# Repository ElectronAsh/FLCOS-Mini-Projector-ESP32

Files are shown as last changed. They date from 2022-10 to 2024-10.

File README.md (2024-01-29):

# FLCOS Mini Projector with ESP32 and Composite input.

WARNING: Please do not build this board yet. There are still some checks to do.

UPDATE: 29th April 2023: I finally bought one of the Jakks toy projectors from eBay US.
I hooked up the USB Logic Analyzer to the "SPI" bus on the projector's FLCOS module.
The projector only ever write to three registers after power-up, then another register to enable the FLCOS after a video signal is detected.

So I did a few tweaks to my Arduino code, and now my own board works, too. ;)

I also confirmed that the AliExpress FLCOS modules DO indeed work fine in the Jakks projector, so they are the same/compatible part.

There are still a few issues to sort out, where the FLCOS won't always turn on when you first plug USB power in, but it will work after pulling
the reset (EN_N) Low on the ESP32, or re-flashing via the Arduino IDE.

I've included a few photos below of the projector showing "Gex" on the 3DO.
This is a PAL 3DO, so I tweaked the Arduino code to fit the projected image better.
(the FLCOS registers will default to NTSC, so I tweaked the values for PAL.)

TODO...

Voltage reg pinouts and ADJ pins (use adjustable and add resistor dividers, or look for fixed-output regs for the BOM?)
FPC connector direction, top contact? (The FLCOS module will be mounted upside-down on the board)
Double-check the JST ZH pinout for the LEDs. DONE
Maybe change the pin header to some sort of socket for the Composite input? DONE
Check availability of all ICs on LCSC or Mouser, digikey etc. DONE
Hunt for parts, create a BOM. DONE
Run ERC and DRC. DONE
Order a few test PCBs. DONE

This is a driver board for the FLCOS mini projector modules on AliExpress...
https://www.aliexpress.com/item/1005003386129982.html

There is a forum post here, with the full datasheet for what appears to be the same FLCOS chip used on the AliExpress module.
https://whycan.com/t_2420.html

("datasheet" is actually the product brief. "cps" has all of the register settings.)

The pinout of the lower flex cable on post #4 of the forum seems to match up with the ribbon on the FLCOS module.

The pinout of the RGB LED cable on the module is a bit strange.
There is no correlation between the wire colours, the silkscreen designators, and the RGB LED chip itself.

I tested the RGB LED with a bench PSU, though, and the pinout on the Eagle schematic *should* be correct now.
I just need to double-check that the JST ZH connector for the LED is not rotated 180-degrees or something.

(it's possible the manufacturer changed the RGB LED for a different one on request, which is why the LED cable pinout doesn't seem to tally with the silkscreen?)

The exact maximum LED current is unknown.
I tested one of the Green LEDs with 160mA at first, and it didn't seem to increase in brightness much above 200mA.

The forward voltage drop of the Blue and Green LEDs was around 3.3 Volts, according to my bench PSU (when current-limiting). (there are two Green LEDs on the die) 

The forward voltage drop of the Red LED was around 2.0 Volts.

The included RGB LED has all of Anodes connected together.
I originally put some LM3404 LED driver ICs on the board, but they wouldn't have worked for a common-Anode RGB LED chip, so I changed those for the LM3414 instead.

The FLCOS module appears to be the same one used in the "JAKKS Eyeclops" toy projector...
https://videotechnology.blogspot.com/2010/11/inside-jakks-pacific-eyeclops-mini.html

Before I received some modules, I did a lot of tracing of the JAKKS PCB to try to confirm the pinout against the TVP5150 TV decoder chip.
The pinout seemed to match up with the forum post above.

There was a discussion on Twitter in 2021 about these modules, too...
https://twitter.com/AshEvans81/status/1498184526236987392?s=20&t=zDXLWlJON1HiXY-NYlLocg

The PCB layout was also discussed on the #lab channel of bitluni's Discord server.

bitluni's awesome ESP32 VGA output project was the reason I wanted to add an ESP32 to the board.
It could make for a neat mini movie player or similar (streaming low-res files from SD card.)

https://github.com/bitluni/ESP32Lib/blob/8f4b1bc9c331546c57c1ee837ac37303b8d8739c/examples/VGADemo14Bit/VGADemo14Bit.ino

(bitluni's code is untested with the FLCOS modules atm, but I think it will work OK with a few tweaks. The FLCOS chip accepts video input as sequential R,G,B bytes.)

I kept the TVP5150 chip on the board, as this is the same chip used in the JAKKS projector.
It outputs standard bt.656 style digital video, and accepts Composite input.

(The TVP5150 can receive both NTSC and PAL Composite, using one 14.318 MHz crystal.)

Only the TVP5150 or ESP32 can drive the FLCOS module at any one time.
The TVP chip can set it's output pins to High-Z (this is done via an I2C register), so it should be possible to keep both the ESP32 and TVP5150 onboard.

Most of the footprint libraries for the ESP32, SD slot, TVP5150, and LM3414 were taken from existing open-source projects.
I don't have the names or links to all of those projects now, but I will add them to the README if I can find them.

I used Eagle 9.0.1 to do the PCB layout.

Build at your own risk!

It does finally "work" now, in terms of getting Composite video to display.
But there are a few issues, as mentioned in the update at the top of this README.

I haven't tried generating video on the ESP32 yet, so I'm not 100% sure that will work without PCB changes.

ElectronAsh. ;)

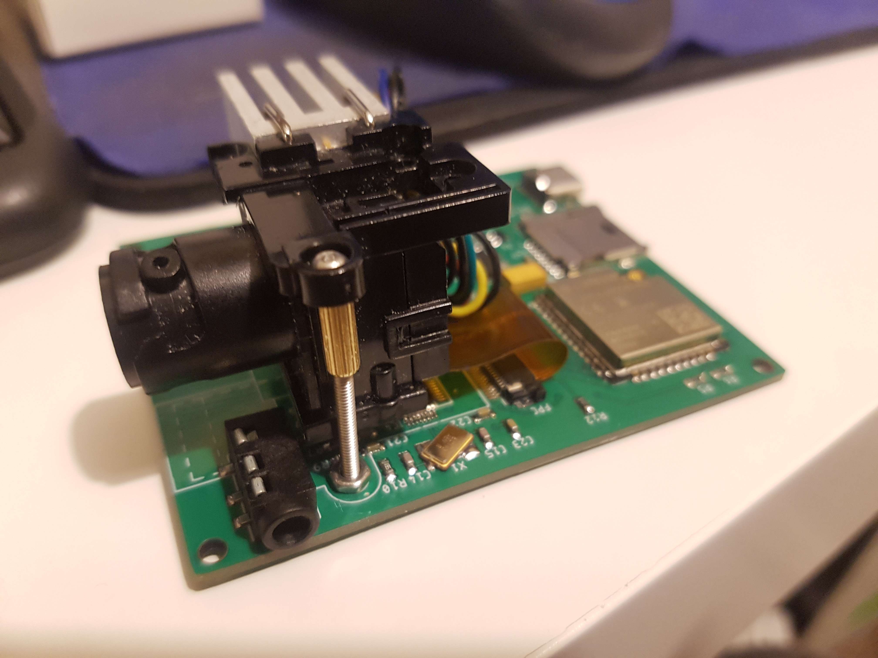
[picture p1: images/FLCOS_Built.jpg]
FLCOS First Light - GEX Logo

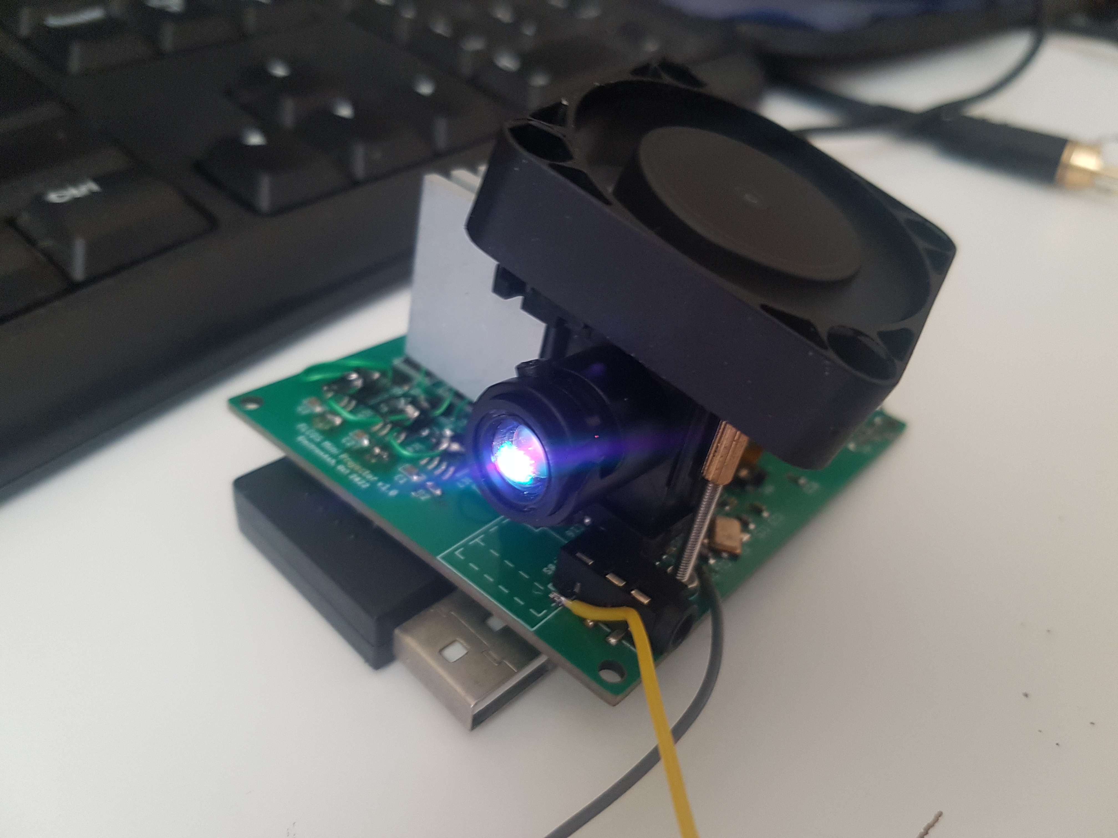
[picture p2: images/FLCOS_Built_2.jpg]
FLCOS First Light - GEX Logo

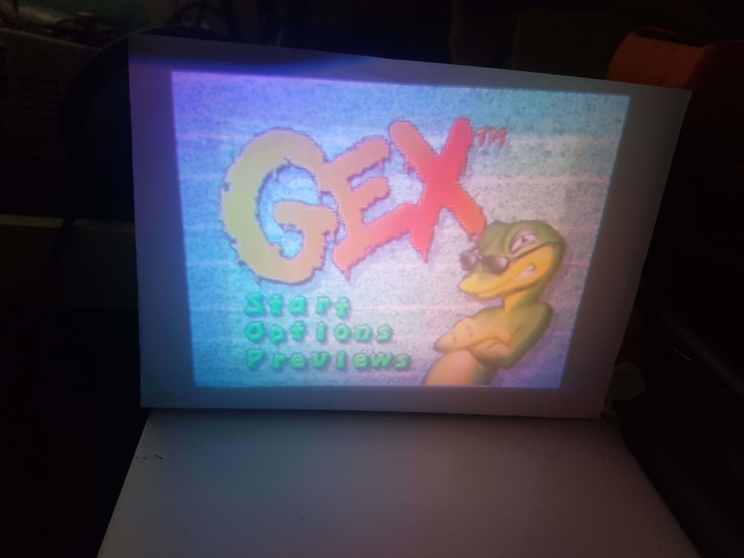
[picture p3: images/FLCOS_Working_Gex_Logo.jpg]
FLCOS First Light - GEX Logo


This was a quick test of the Green LEDs. FLCOS chip itself is not powered.

Both Green LEDs in parallel, 220mA, lens was 150mm from the "screen".
The box is only 90mm wide.

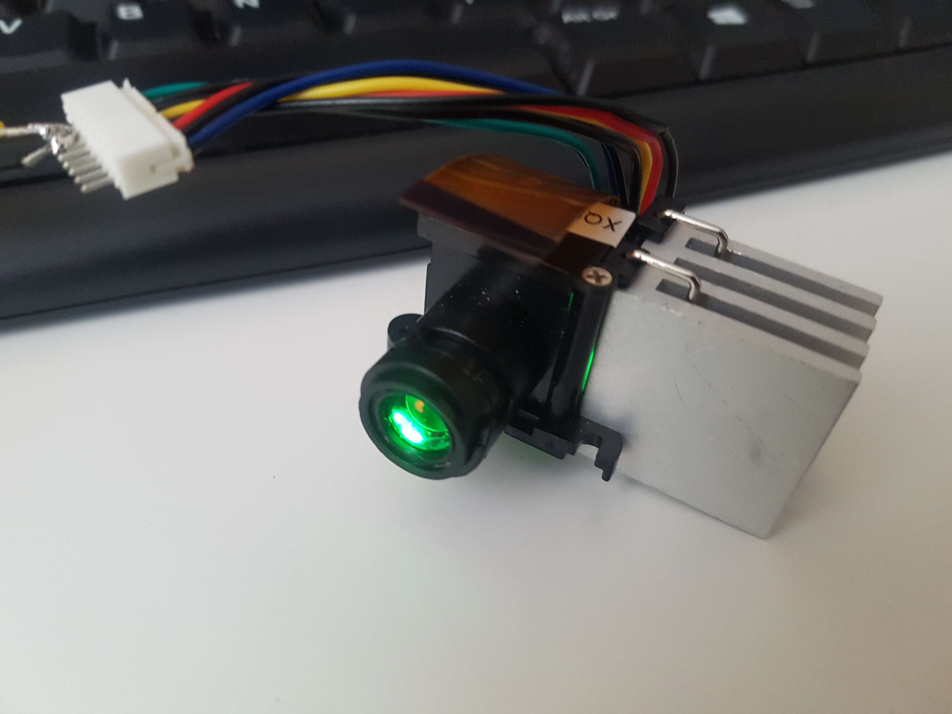
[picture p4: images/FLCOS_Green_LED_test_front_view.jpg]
FLCOS Green LED test front view

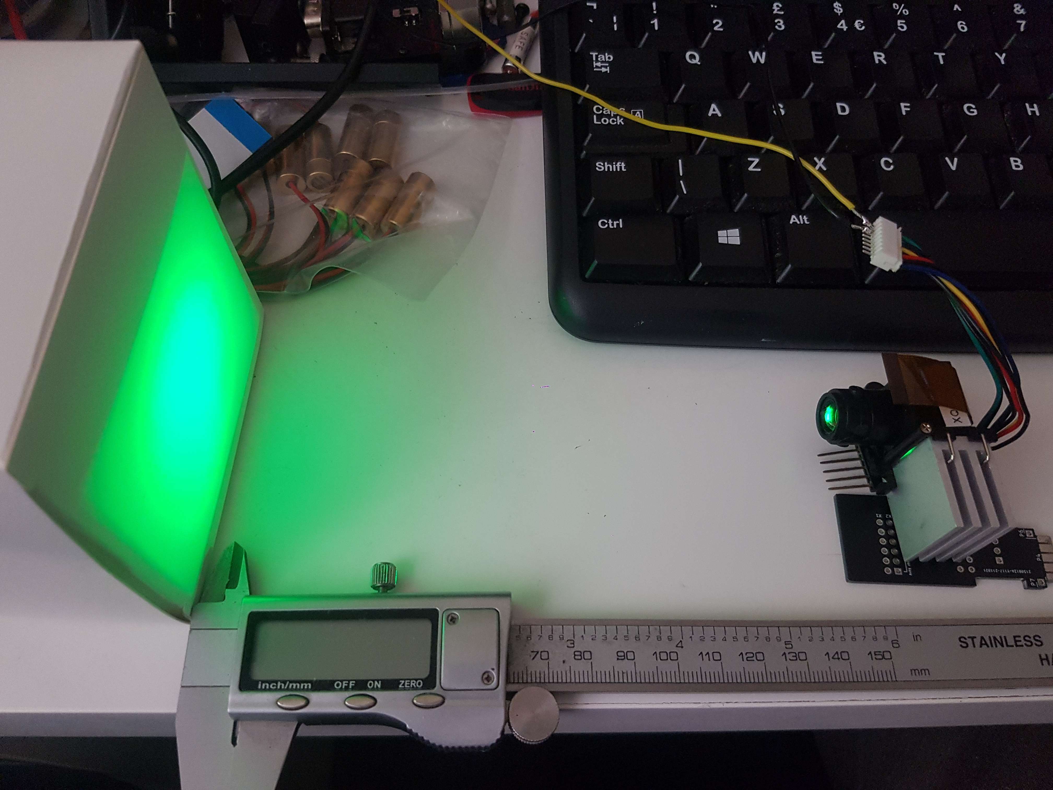
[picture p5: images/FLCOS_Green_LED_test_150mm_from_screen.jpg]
FLCOS Green LED test 150mm from screen

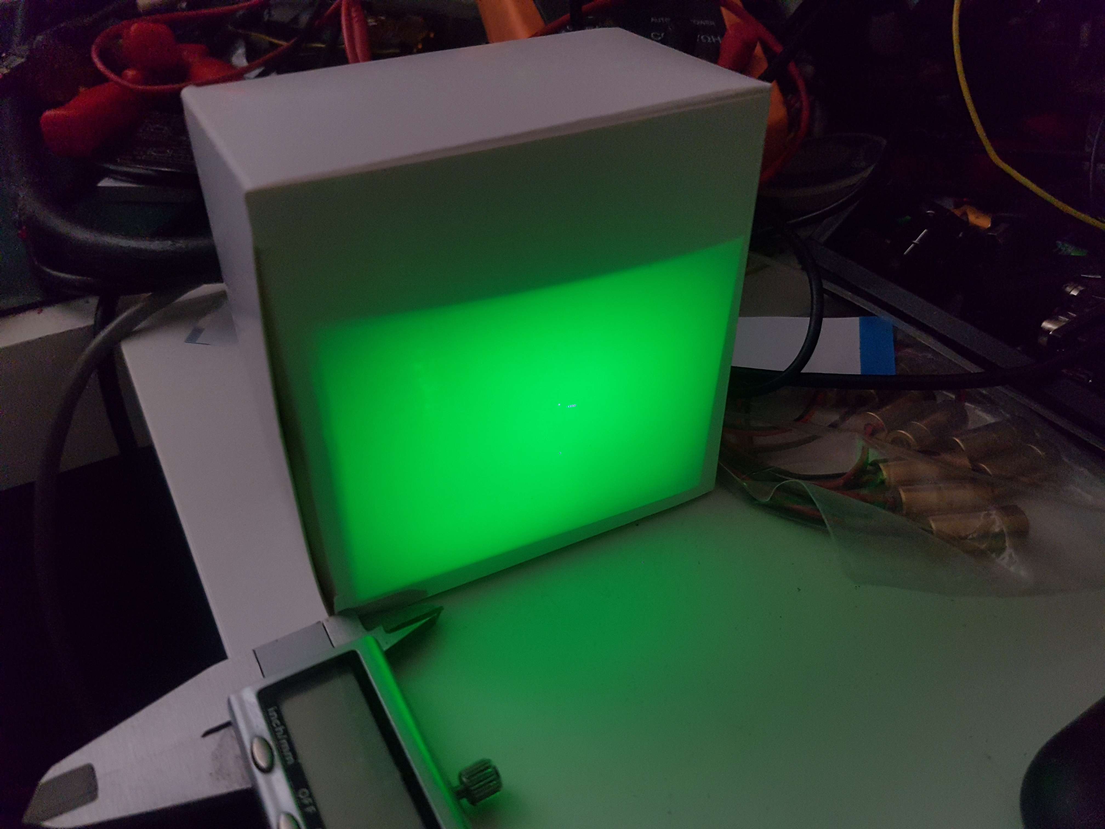
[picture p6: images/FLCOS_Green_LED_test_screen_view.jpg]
FLCOS Green LED test screen view


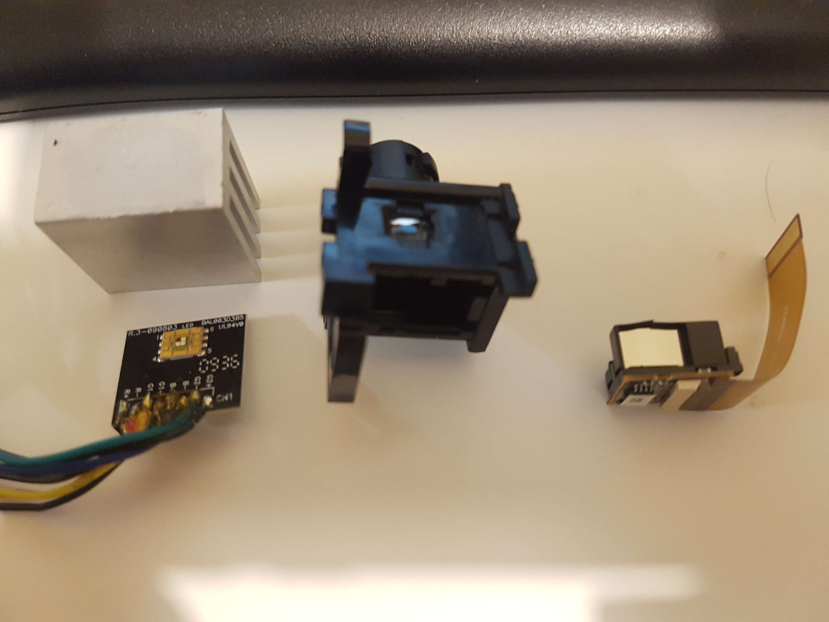
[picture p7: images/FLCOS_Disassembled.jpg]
FLCOS Module Disassembled


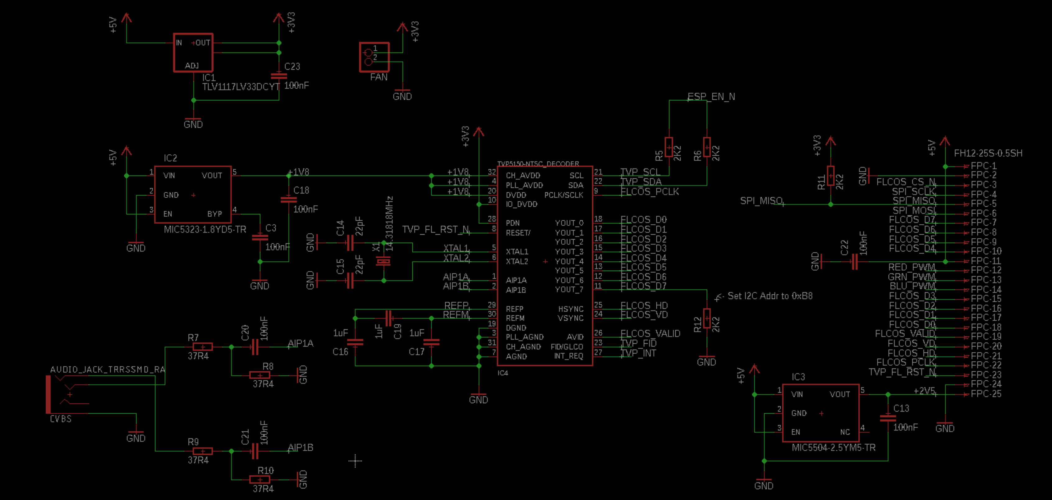
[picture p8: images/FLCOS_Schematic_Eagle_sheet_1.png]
FLCOS Schematic Eagle sheet 1

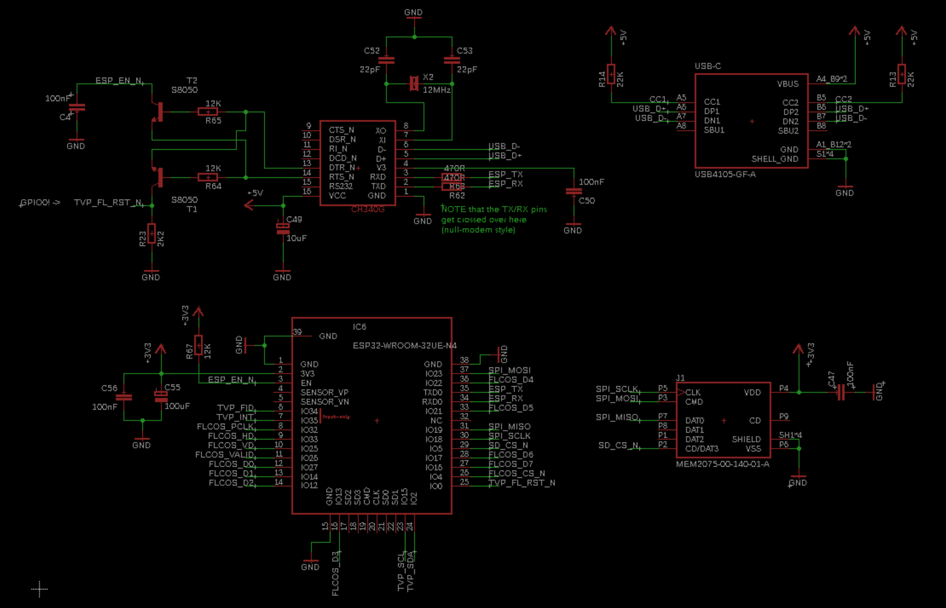
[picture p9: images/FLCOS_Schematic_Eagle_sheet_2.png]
FLCOS Schematic Eagle sheet 2

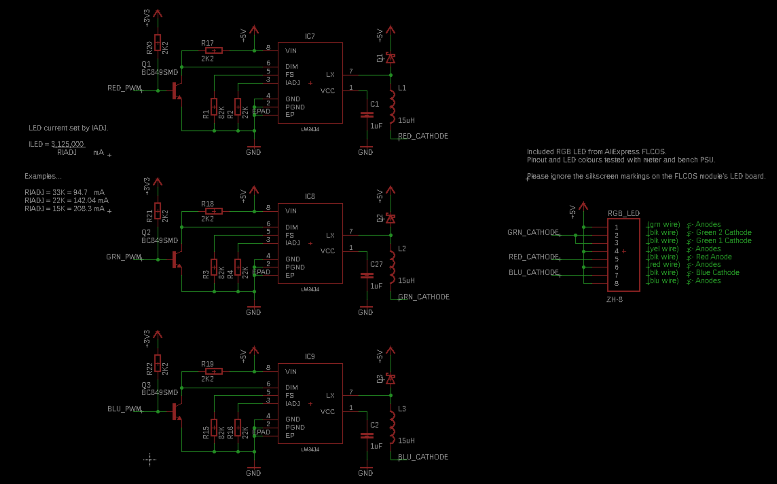
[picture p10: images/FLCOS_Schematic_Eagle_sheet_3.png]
FLCOS Schematic Eagle sheet 3

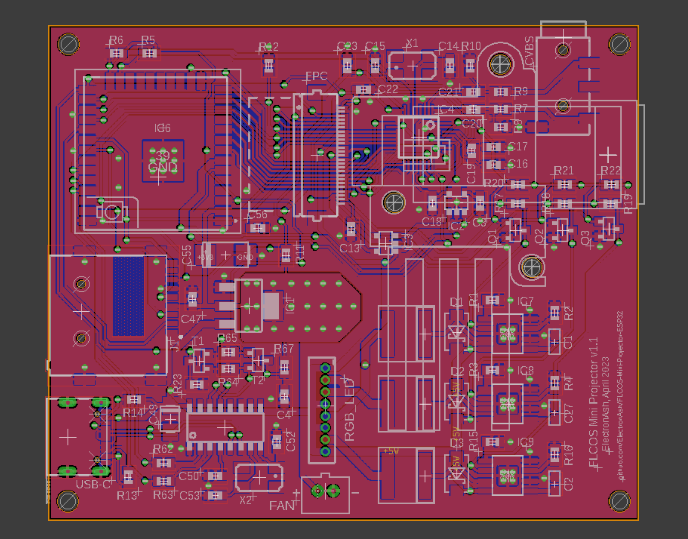
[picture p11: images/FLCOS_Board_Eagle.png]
FLCOS Green LED test - front view


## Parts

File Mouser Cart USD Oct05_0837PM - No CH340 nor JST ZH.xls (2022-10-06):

SHOPPING CART
This is not an invoice
05-Oct-22 20:37:14
 | Mouser # | Mfr. # | Manufacturer | Customer # | Description | RoHS | Lifecycle | Order Qty. | Price (USD) | Ext.: (USD)
1 | 187-CL10B105KA8NNNL | CL10B105KA8NNNL | Samsung Electro-Mechanics |  | Multilayer Ceramic Capacitors MLCC - SMD/SMT 1uF+/-10% 25V X7R 16 0603 | RoHS Compliant |  | 6 | $0.10 | $0.60
2 | 187-CL10B104MA8NNWC | CL10B104MA8NNWC | Samsung Electro-Mechanics |  | Multilayer Ceramic Capacitors MLCC - SMD/SMT 100nF+/-20% 25V X7R 0603 | RoHS Compliant |  | 10 | $0.031 | $0.31
3 | 187-CL10C220JB8NNWC | CL10C220JB8NNWC | Samsung Electro-Mechanics |  | Multilayer Ceramic Capacitors MLCC - SMD/SMT 22pFC0G +/-5% 50v 06 0603 | RoHS Compliant | New Product | 4 | $0.10 | $0.40
4 | 581-TAJB106M016R | TAJB106M016RNJ | KYOCERA AVX |  | Tantalum Capacitors - Solid SMD 16V 10uF 20% 1210 ESR= 2.8 Ohm | RoHS Compliant |  | 1 | $0.37 | $0.37
5 | 581-TAJC107K006SNJ | TAJC107K006SNJ | KYOCERA AVX |  | Tantalum Capacitors - Solid SMD 6.3V 100uF 2312 ESR=900mOhms 10% | RoHS Compliant |  | 1 | $0.67 | $0.67
6 | 603-RT0603DRE0782KL | RT0603DRE0782KL | YAGEO |  | Thin Film Resistors - SMD | RoHS Compliant By Exemption |  | 3 | $0.10 | $0.30
7 | 603-RT0603DRE0722KL | RT0603DRE0722KL | YAGEO |  | Thin Film Resistors - SMD 22K Ohm 0.5% 1/10W 75 Volts 50ppm | RoHS Compliant By Exemption |  | 5 | $0.12 | $0.60
8 | 603-RT0603DRE072K2L | RT0603DRE072K2L | YAGEO |  | Thin Film Resistors - SMD 2.2K Ohm 0.5% 1/10W 75 Volts 50ppm | RoHS Compliant By Exemption |  | 4 | $0.11 | $0.44
9 | 603-RC0603FR-0737R4L | RC0603FR-0737R4L | YAGEO |  | Thick Film Resistors - SMD 37.4 Ohms 100 mW 0603 1% | RoHS Compliant By Exemption |  | 5 | $0.10 | $0.50
10 | 603-RT0603FRE07470RL | RT0603FRE07470RL | YAGEO |  | Thin Film Resistors - SMD 1/10W 470 ohm 1% 50ppm | RoHS Compliant By Exemption |  | 2 | $0.10 | $0.20
11 | 603-RT0603FRE0712KL | RT0603FRE0712KL | YAGEO |  | Thin Film Resistors - SMD 1/10W 12K ohm 1% 50ppm | RoHS Compliant By Exemption |  | 2 | $0.10 | $0.20
12 | 875-TYS6028150M-10 | TYS6028150M-10 | Laird Performance Materials |  | Power Inductors - SMD 15uH 20% -40C +125C | RoHS Compliant |  | 3 | $0.53 | $1.59
13 | 241-SB34AFCAUR1000A1 | SB34AFC-AU_R1_000A1 | Panjit |  | Schottky Diodes & Rectifiers 40V SchottkyF-C 3A | RoHS Compliant By Exemption | New Product | 3 | $0.45 | $1.35
14 | 833-MMSS8050-H-TP | MMSS8050-H-TP | Micro Commercial Components (MCC) |  | Bipolar Transistors - BJT 625mW, 25V, 1500mA | RoHS Compliant |  | 2 | $0.21 | $0.42
15 | 595-TLV1117LV33DCYT | TLV1117LV33DCYT | Texas Instruments |  | LDO Voltage Regulators 1A,Pos Fix Vltg LDO Linear Reg | RoHS Compliant |  | 1 | $1.14 | $1.14
16 | 998-MIC5323-1.8YD5TR | MIC5323-1.8YD5-TR | Microchip |  | LDO Voltage Regulators 300mA uCap ULDO High PSRR Low Noise Regulator | RoHS Compliant |  | 1 | $0.68 | $0.68
17 | 998-MIC5504-2.5YM5TR | MIC5504-2.5YM5-TR | Microchip |  | LDO Voltage Regulators Single 300mA LDO with Enable Pull-Down & Auto Discharge | RoHS Compliant |  | 1 | $0.16 | $0.16
18 | 926-LM3414HVMR/NOPB | LM3414HVMR/NOPB | Texas Instruments |  | LED Lighting Drivers COMM ANODE CAP CONST CRNT BUCK LED DRVR | RoHS Compliant |  | 3 | $2.48 | $7.44
19 | 595-TVP5150AM1PBSR | TVP5150AM1PBSR | Texas Instruments |  | Video ICs Ultralo Pwr NTSC/PAL SECAM Vid Decoder | RoHS Compliant |  | 1 | $6.56 | $6.56
20 | 356-ESP32WRM32UE32UH | ESP32-WROOM-32UE-N4 | Espressif |  | Multiprotocol Modules SMD module ESP32-WROOM-32UE, ESP32-D0WD-V3, ESP32 ECO V3, 4 MB SPI flash, IPEX antenna connector | RoHS Compliant |  | 1 | $3.00 | $3.00
21 | 640-MEM20750014001A | MEM2075-00-140-01-A | Global Connector Technology (GCT) |  | Memory Card Connectors Micro SD Push-Push, SMT, 1.40mm Profile, With Peg, Open Switch, T&R | RoHS Compliant | New Product | 1 | $1.96 | $1.96
22 | 640-USB4105-GF-A | USB4105-GF-A | Global Connector Technology (GCT) |  | USB Connectors USB Type C,2.0, Rec,SMT, 0.95mmTH Shell Stakes,G/F,RA,Top Mnt,T&R | RoHS Compliant | New Product | 1 | $0.81 | $0.81
23 | 649-SFV25R-2STE1HLF | SFV25R-2STE1HLF | FCI / Amphenol |  | FFC & FPC Connectors FFC/FPC CONN | RoHS Compliant |  | 1 | $0.62 | $0.62
24 | 520-ECS143-20-23A-EN | ECS-143-20-23A-EN-TR | ECS |  | Crystals 14.31818MHz 20pF ECX-64A | RoHS Compliant |  | 1 | $1.13 | $1.13
25 | 520-120-12-36AGN-TR3 | ECS-120-12-36-AGN-TR3 | ECS |  | Crystals 12MHz,CL 12,TOL +/-25 ppm,STAB +/-30 ppm,-40 +85 C,ESR 150O | RoHS Compliant | New Product | 1 | $0.37 | $0.37
26 | 474-PRT-12639 | PRT-12639 | SparkFun Electronics |  | SparkFun Accessories Audio Jack - 3.5mm TRRS (SMD) |  |  | 1 | $0.95 | $0.95
By submitting your order you agree to these terms and conditions. (https://www.mouser.com/saleterms) |  |  |  |  |  |  |  |  | Merchandise: | $32.77
Prices are reflected at the date and time shown. |  |  |  |  |  |  |  |  | Shipping Charge: | $7.99

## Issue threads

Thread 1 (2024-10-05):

How I can control this FLCoS display using esp32?

FeatheryVlad, 2024-10-05:
Hello! Could you please tell me how I can control this FLCoS display using esp32? And Is it possible to get by with just one board based on the esp32-s3 chip?

Also I really like your project, I just can’t imagine how long it took to develop it.

ElectronAsh, 2024-10-05:
Hi,

I never did get around to driving the FLCOS module from the ESP32.
I only ever tested it using the PAL/NTSC decoder on the board.

The FLCOS module needs a bt.656 style video stream, which is an 8-bit bus, commonly used in TV broadcast, cable boxes, DVD players, etc.

Sometimes bt.656 can have separate syncs, or the sync is actually embedded into the 8-bit data.

I'm not sure where to start with writing the ESP32 code for that, sorry.

(I was hoping maybe bitluni might be interested, but he's often super busy. hehe)

Regards,
Ash.

FeatheryVlad, 2024-10-05:
Thank you!

Sorry, but unfortunately I have no experience working with a display other than those usually sold on Aliexpress (spi, i2c, etc.)
That’s why I had this question, yes, I looked at your code and board diagram many times (even very many times), but I still can’t understand how it works for you

Also I would like to know more about BT.656 from you, since there is little useful information on the Internet, maybe it has something to do with my region/country

Please, I really want to run it :)

FeatheryVlad, 2024-10-06:
Hi,

I literally can't do anything, neither write registers via SPI, much less send a frame.
I'm using ESP-IDF to flash my esp32-s3-zero, but still can't get SPI configured correctly even with your code and Arduino IDE.

I also searched online, but didn't find anything similar to this repository.

Please forgive me for these requests, I literally don't know who I could contact with such a question😭.

Regards,
Vlad.

ElectronAsh, 2024-10-07:
Hi,

My board uses a TVP5150, which is a PAL/NTSC decoder chip.

Currently, the ESP32 on the board is used purely to configure some basic commands on the FLCOS module at power-up.

The ESP32 itself does not drive the video signals on the FLCOS.
I never got quite that far with the project.

Instead, I input Composite Video into the TVP5150.
That chip sends the bt.656 style video to the FLCOS module directly.
The ESP32 doesn't get involved at all after that.

I'm not sure where to start with using the ESP32 to send video to the FLCOS.
I was looking at using bitluni's VGA code as a basis, then trying to add the bt.656 stuff to the output to the FLCOS.

The TVP5150 can output bt.656 with or without embedded Syncs.
I believe I was using separate Hsync/Vsync to drive the FLCOS.

Even when using Composite Video input and the TVP chip, I had some trouble getting the FLCOS to initialize correctly every time.

I had to solder a Reset button to the ESP32 on my board, and hit Reset just after power-up, then the FLCOS sprang to life.

I used the Composite video output from a 3DO console to test things.

Unless you are using the TVP or a board like mine, I think it could be hard to send video direct from an ESP32.
In theory, though, you could try sending "raw" RGB values to the FLCOS, and generate Pclk/Hsync/Vsync/Valid signals, and it might then display something?

(then you would need to convert those RGB values into Y,U,V samples, to get the correct colours on the FLCOS.)

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

ElectronAsh, 2024-10-07:
Oh, btw...

I posted quite a lot of info on the FLCOS project on "The Coriolis Effect" Discord.

Here is an invite link, I believe it is free-to-join...
https://discord.gg/sRQVjWkK

(if the link doesn't work for you, somebody else has probably clicked on it already, so please let me know. lol)

You should fine a whole thread on the "projects-threaded" channel called "FLCOS Mini Projector".

1w0, 2025-02-03:
Hi, thanks for sharing the project and insights, wondering if I can join the server as well? Thanks!

By the way, I haven't been able to access the datasheet as mentioned being in the forum, will be great if there is any alternative 🙏

FeatheryVlad, 2025-02-10:
Hi,
As far as I remember this is exactly the datasheet:
http://file.whycan.com/files/members/1606/ldm_0201_e3_cps.pdf

ElectronAsh, 2025-02-11:
Here's an invite link to the Discord server.

But if anyone else clicks it in the meantime, I think it stops working?

https://discord.gg/89Uxe6wU

AFAIK, it's a public server anyway.

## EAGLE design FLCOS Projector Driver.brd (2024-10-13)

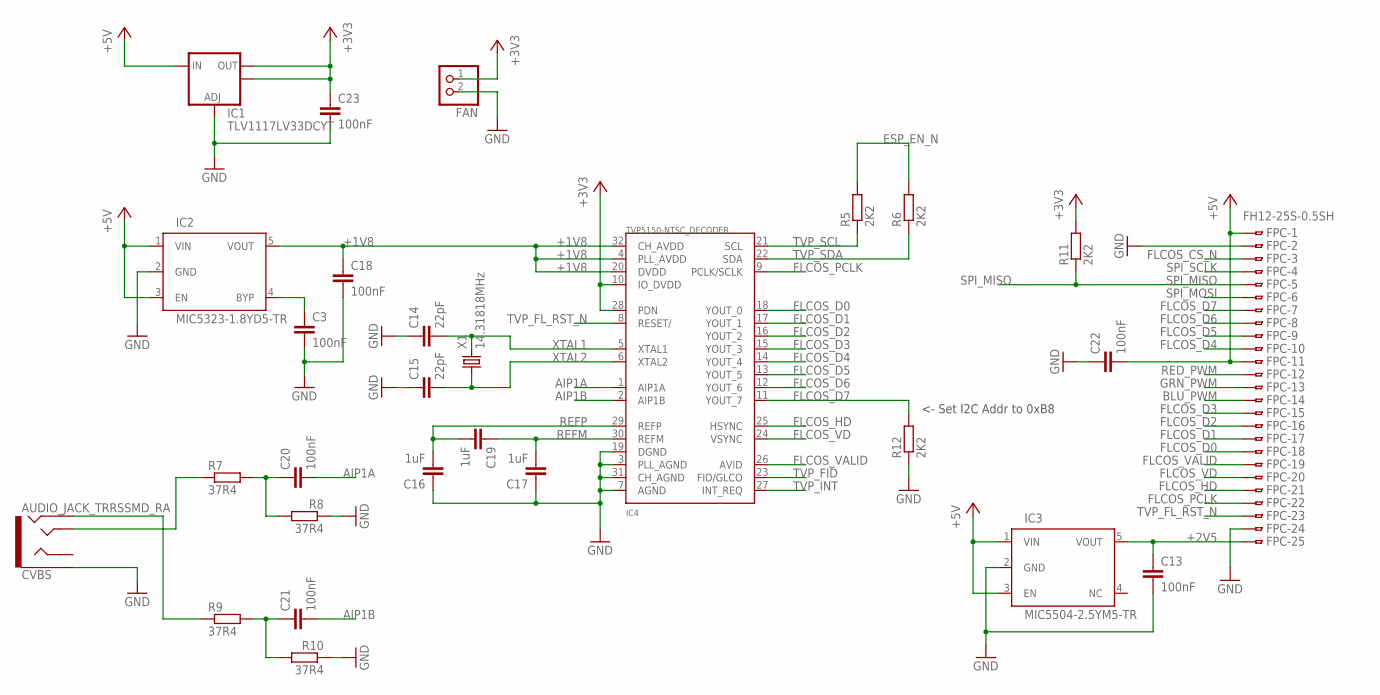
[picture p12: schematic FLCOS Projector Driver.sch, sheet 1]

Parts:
C3, C13, C18, C20, C21, C22, C23: 100nF; C0603
C14, C15: 22pF; C0603
C16, C17, C19: 1uF; C0603
CVBS: AUDIO_JACK_TRRSSMD_RA; AUDIO_JACK_3.5MM_TRRS_SMD_RA
FAN: JST_2PIN-THM; JST-PH-2-THM
FPC: FH12-25S-0.5SH
IC1: TLV1117LV33DCYT; SOT223
IC2: MIC5323-1.8YD5-TR; SOT23-5
IC3: MIC5504-2.5YM5-TR; SOT23-5
IC4: TVP5150-NTSC_DECODER; TQFP32-5MM
R5, R6, R11, R12: 2K2; R0603
R7, R8, R9, R10: 37R4; R0603
X1: 14.31818MHz; CTS406

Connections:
+1V8: C18.1, IC2.5 (VOUT), IC4.4 (PLL_AVDD), IC4.20 (DVDD), IC4.32 (CH_AVDD)
+2V5: C13.1, FPC.25, IC3.5 (VOUT)
+3V3: C23.1, FAN.1 (2), IC1.2 (OUT), IC1.4 (OUT), IC4.10 (IO_DVDD), IC4.28 (PDN), R11.2; also elsewhere on the board
+5V: C22.2, FPC.1, FPC.11, IC1.3 (IN), IC2.1 (VIN), IC2.3 (EN), IC3.1 (VIN), IC3.3 (EN); also elsewhere on the board
AIP1A: C20.2, IC4.1 (AIP1A)
AIP1B: C21.2, IC4.2 (AIP1B)
BLU_PWM: FPC.14; also elsewhere on the board
ESP_EN_N: R5.2, R6.2; also elsewhere on the board
FLCOS_CS_N: FPC.3; also elsewhere on the board
FLCOS_D0: FPC.18, IC4.18 (YOUT_0); also elsewhere on the board
FLCOS_D1: FPC.17, IC4.17 (YOUT_1); also elsewhere on the board
FLCOS_D2: FPC.16, IC4.16 (YOUT_2); also elsewhere on the board
FLCOS_D3: FPC.15, IC4.15 (YOUT_3); also elsewhere on the board
FLCOS_D4: FPC.10, IC4.14 (YOUT_4); also elsewhere on the board
FLCOS_D5: FPC.9, IC4.13 (YOUT_5); also elsewhere on the board
FLCOS_D6: FPC.8, IC4.12 (YOUT_6); also elsewhere on the board
FLCOS_D7: FPC.7, IC4.11 (YOUT_7), R12.2; also elsewhere on the board
FLCOS_HD: FPC.21, IC4.25 (HSYNC); also elsewhere on the board
FLCOS_PCLK: FPC.22, IC4.9 (PCLK/SCLK); also elsewhere on the board
FLCOS_VALID: FPC.19, IC4.26 (AVID); also elsewhere on the board
FLCOS_VD: FPC.20, IC4.24 (VSYNC); also elsewhere on the board
GND: C3.2, C13.2, C14.1, C15.1, C16.1, C17.1, C18.2, C22.1, C23.2, CVBS.EARTH, FAN.2 (1), FPC.2, FPC.24, IC1.1 (ADJ), IC2.2 (GND), IC3.2 (GND), IC4.3 (PLL_AGND), IC4.7 (AGND), IC4.19 (DGND), IC4.31 (CH_AGND), R8.1, R10.1, R12.1; also elsewhere on the board
GRN_PWM: FPC.13; also elsewhere on the board
unnamed: C3.1, IC2.4 (BYP)
unnamed: C21.1, R9.2, R10.2
unnamed: C20.1, R7.2, R8.2
unnamed: CVBS.TIP, R7.1
unnamed: CVBS.RING2, R9.1
RED_PWM: FPC.12; also elsewhere on the board
REFM: C17.2, C19.1, IC4.30 (REFM)
REFP: C16.2, C19.2, IC4.29 (REFP)
SPI_MISO: FPC.5, R11.1; also elsewhere on the board
SPI_MOSI: FPC.6; also elsewhere on the board
SPI_SCLK: FPC.4; also elsewhere on the board
TVP_FID: IC4.23 (FID/GLCO); also elsewhere on the board
TVP_FL_RST_N: FPC.23, IC4.8 (RESET/); also elsewhere on the board
TVP_INT: IC4.27 (INT_REQ); also elsewhere on the board
TVP_SCL: IC4.21 (SCL), R5.1; also elsewhere on the board
TVP_SDA: IC4.22 (SDA), R6.1; also elsewhere on the board
XTAL1: C14.2, IC4.5 (XTAL1), X1.3 (2)
XTAL2: C15.2, IC4.6 (XTAL2), X1.1

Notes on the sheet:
<- Set I2C Addr to 0xB8

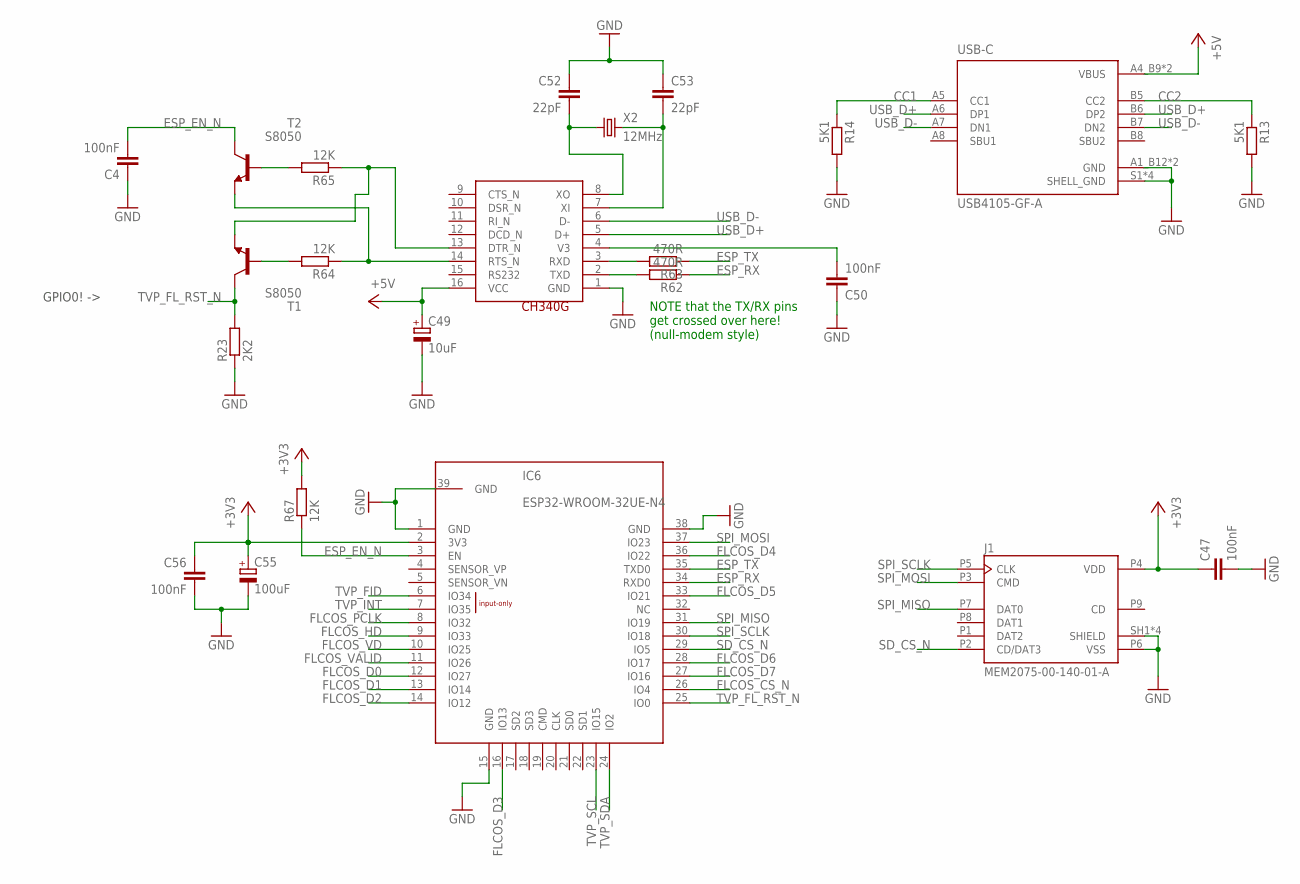
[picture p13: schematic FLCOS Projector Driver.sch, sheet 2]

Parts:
C4, C47, C50, C56: 100nF; C0603
C49: 10uF; B/3528-21W
C52, C53: 22pF; C0603
C55: 100uF; C/6032-28R
IC5: CH340G; SOIC16
IC6: ESP32-WROOM-32UE-N4; ESP32WROOM32D
J1: MEM2075-00-140-01-A; GCT_MEM2075-00-140-01-A
R13, R14: 5K1; R0603
R23: 2K2; R0603
R62, R63: 470R; R0603
R64, R65, R67: 12K; R0603
T1, T2: S8050; SOT23-BEC
USB-C: USB4105-GF-A; GCT_USB4105-GF-A
X2: 12MHz; CTS406

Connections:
+3V3: C47.1, C55.+, C56.1, IC6.2 (3V3), J1.P4 (VDD), R67.2; also elsewhere on the board
+5V: C49.+, IC5.16 (VCC), USB-C.A4_B9 (VBUS), USB-C.B4_A9 (VBUS); also elsewhere on the board
CC1: R14.1, USB-C.A5 (CC1)
CC2: R13.1, USB-C.B5 (CC2)
ESP_EN_N: C4.2, IC6.3 (EN), R67.1, T2.C; also elsewhere on the board
ESP_RX: IC6.34 (RXD0), R62.1
ESP_TX: IC6.35 (TXD0), R63.1
FLCOS_CS_N: IC6.26 (IO4); also elsewhere on the board
FLCOS_D0: IC6.12 (IO27); also elsewhere on the board
FLCOS_D1: IC6.13 (IO14); also elsewhere on the board
FLCOS_D2: IC6.14 (IO12); also elsewhere on the board
FLCOS_D3: IC6.16 (IO13); also elsewhere on the board
FLCOS_D4: IC6.36 (IO22); also elsewhere on the board
FLCOS_D5: IC6.33 (IO21); also elsewhere on the board
FLCOS_D6: IC6.28 (IO17); also elsewhere on the board
FLCOS_D7: IC6.27 (IO16); also elsewhere on the board
FLCOS_HD: IC6.9 (IO33); also elsewhere on the board
FLCOS_PCLK: IC6.8 (IO32); also elsewhere on the board
FLCOS_VALID: IC6.11 (IO26); also elsewhere on the board
FLCOS_VD: IC6.10 (IO25); also elsewhere on the board
GND: C4.1, C47.2, C49.-, C50.1, C52.1, C53.1, C55.-, C56.2, IC5.1 (GND), IC6.1 (GND), IC6.15 (GND), IC6.38 (GND), IC6.39 (GND), J1.P6 (VSS), J1.SH1 (SHIELD), J1.SH2 (SHIELD), J1.SH3 (SHIELD), J1.SH4 (SHIELD), R13.2, R14.2, R23.1, USB-C.A1_B12 (GND), USB-C.B1_A12 (GND), USB-C.S1 (SHELL_GND), USB-C.S2 (SHELL_GND), USB-C.S3 (SHELL_GND), USB-C.S4 (SHELL_GND); also elsewhere on the board
unnamed: IC5.2 (TXD), R62.2
unnamed: IC5.3 (RXD), R63.2
unnamed: R64.2, T1.B
unnamed: R65.2, T2.B
unnamed: IC5.14 (RTS_N), R64.1, T2.E
unnamed: IC5.13 (DTR_N), R65.1, T1.E
unnamed: C50.2, IC5.4 (V3)
unnamed: C53.2, IC5.7 (XI), X2.3 (2)
unnamed: C52.2, IC5.8 (XO), X2.1
SD_CS_N: IC6.29 (IO5), J1.P2 (CD/DAT3)
SPI_MISO: IC6.31 (IO19), J1.P7 (DAT0); also elsewhere on the board
SPI_MOSI: IC6.37 (IO23), J1.P3 (CMD); also elsewhere on the board
SPI_SCLK: IC6.30 (IO18), J1.P5 (CLK); also elsewhere on the board
TVP_FID: IC6.6 (IO34); also elsewhere on the board
TVP_FL_RST_N: IC6.25 (IO0), R23.2, T1.C; also elsewhere on the board
TVP_INT: IC6.7 (IO35); also elsewhere on the board
TVP_SCL: IC6.23 (IO15); also elsewhere on the board
TVP_SDA: IC6.24 (IO2); also elsewhere on the board
USB_D+: IC5.5 (D+), USB-C.A6 (DP1), USB-C.B6 (DP2)
USB_D-: IC5.6 (D-), USB-C.A7 (DN1), USB-C.B7 (DN2)

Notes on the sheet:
NOTE that the TX/RX pins get crossed over here! (null-modem style)
GPIO0! ->

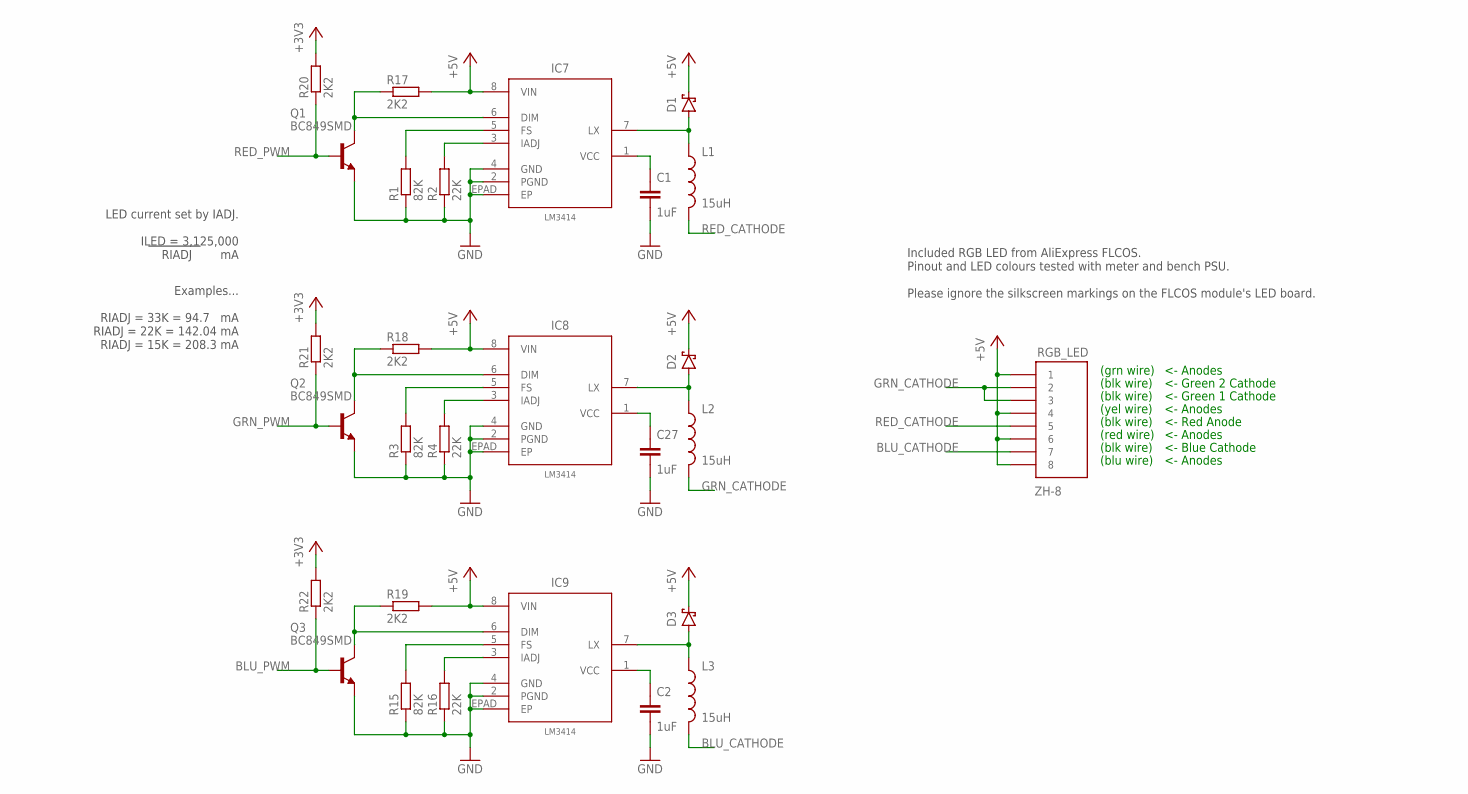
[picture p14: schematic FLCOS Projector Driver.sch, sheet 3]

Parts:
C1, C2, C27: 1uF; C0603
D1, D2, D3: "SB34AFC-AU_R1_000A1 SB34AFC-AU_R1_000A1"; SMA-DIODE-SCHOTTKY
IC7, IC8, IC9: LM3414; SO08-PAD
L1, L2, L3: 15uH; TAIYO-YUDEN-6X6X2.8
Q1, Q2, Q3: BC849SMD; SOT23-BEC
R1, R3, R15: 82K; R0603
R2, R4, R16: 22K; R0603
R17, R18, R19, R20, R21, R22: 2K2; R0603
RGB_LED: ZH-8

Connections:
+3V3: R20.2, R21.2, R22.2; also elsewhere on the board
+5V: D1.C, D2.C, D3.C, IC7.8 (VIN), IC8.8 (VIN), IC9.8 (VIN), R17.2, R18.2, R19.2, RGB_LED.1, RGB_LED.4, RGB_LED.6, RGB_LED.8; also elsewhere on the board
BLU_CATHODE: L3.2, RGB_LED.7
BLU_PWM: Q3.B, R22.1; also elsewhere on the board
GND: C1.2, C2.2, C27.2, IC7.2 (PGND), IC7.4 (GND), IC7.EPAD (EP), IC8.2 (PGND), IC8.4 (GND), IC8.EPAD (EP), IC9.2 (PGND), IC9.4 (GND), IC9.EPAD (EP), Q1.E, Q2.E, Q3.E, R1.1, R2.1, R3.1, R4.1, R15.1, R16.1; also elsewhere on the board
GRN_CATHODE: L2.2, RGB_LED.2, RGB_LED.3
GRN_PWM: Q2.B, R21.1; also elsewhere on the board
unnamed: IC7.6 (DIM), Q1.C, R17.1
unnamed: IC7.3 (IADJ), R2.2
unnamed: IC7.5 (FS), R1.2
unnamed: C1.1, IC7.1 (VCC)
unnamed: D1.A, IC7.7 (LX), L1.1
unnamed: IC9.3 (IADJ), R16.2
unnamed: IC9.5 (FS), R15.2
unnamed: C2.1, IC9.1 (VCC)
unnamed: D3.A, IC9.7 (LX), L3.1
unnamed: IC8.6 (DIM), Q2.C, R18.1
unnamed: IC9.6 (DIM), Q3.C, R19.1
unnamed: IC8.3 (IADJ), R4.2
unnamed: IC8.5 (FS), R3.2
unnamed: C27.1, IC8.1 (VCC)
unnamed: D2.A, IC8.7 (LX), L2.1
RED_CATHODE: L1.2, RGB_LED.5
RED_PWM: Q1.B, R20.1; also elsewhere on the board

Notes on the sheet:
(grn wire)
(blk wire)
(yel wire)
(red wire)
(blu wire)
<- Blue Cathode
<- Green 1 Cathode
<- Green 2 Cathode
<- Anodes
<- Red Anode
Included RGB LED from AliExpress FLCOS. Pinout and LED colours tested with meter and bench PSU. Please ignore the silkscreen markings on the FLCOS module's LED board.
LED current set by IADJ. ILED = 3,125,000 RIADJ mA
Examples... RIADJ = 33K = 94.7 mA RIADJ = 22K = 142.04 mA RIADJ = 15K = 208.3 mA

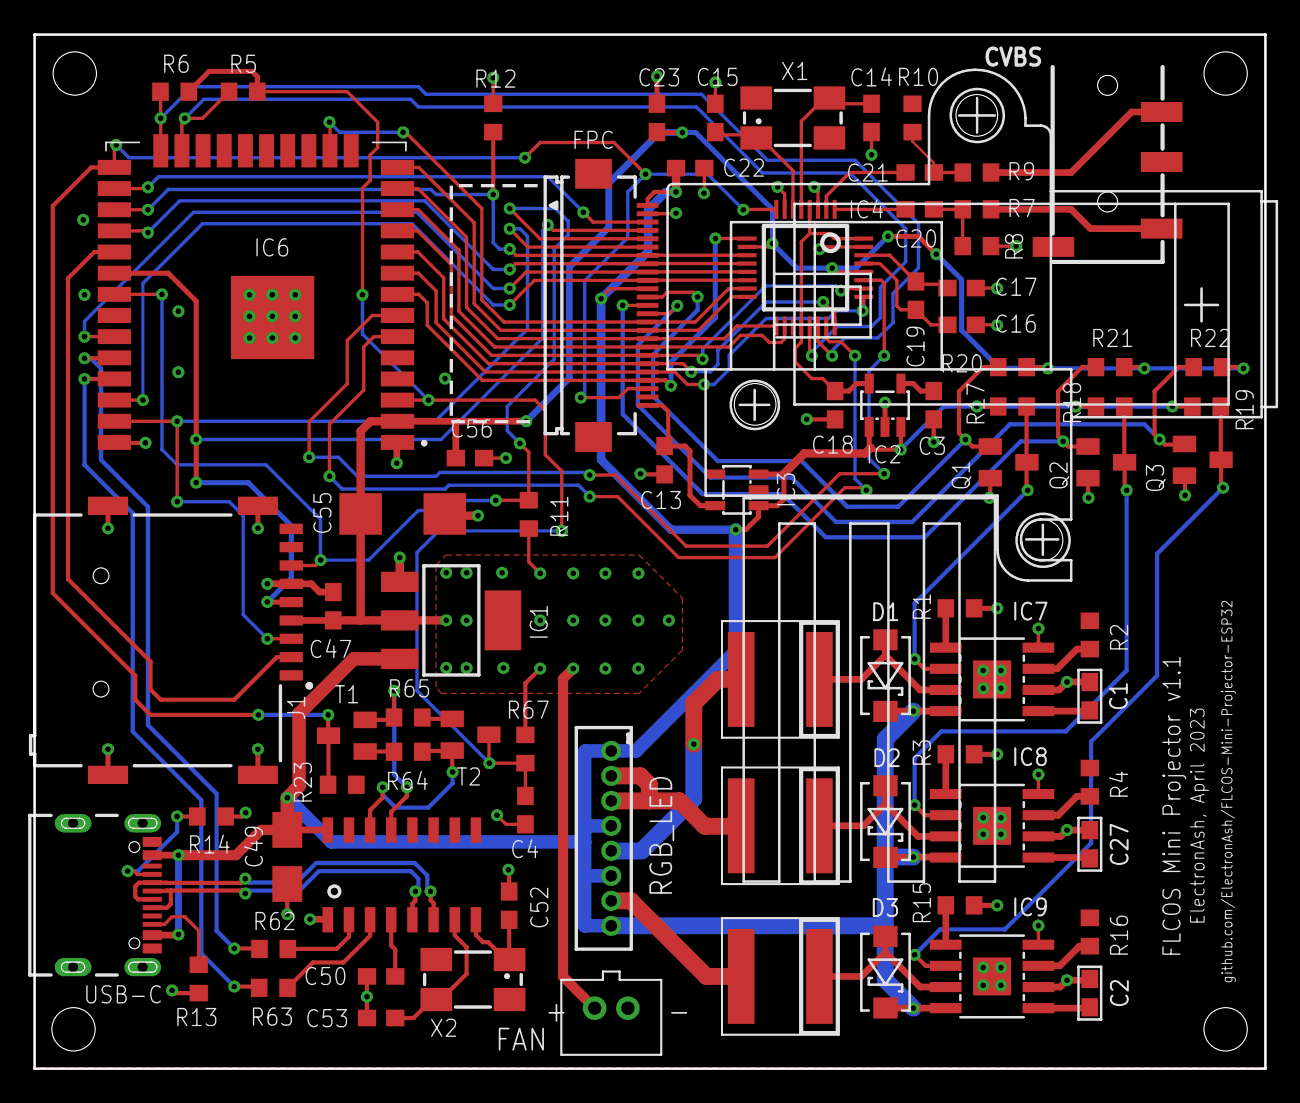
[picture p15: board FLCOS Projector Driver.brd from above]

Board: 2 copper layers, 73.9 x 62.1 mm, 80 parts (0 on the bottom side), 75 nets.

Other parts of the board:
U$2: FLCOS_PROJ_OUTLINE

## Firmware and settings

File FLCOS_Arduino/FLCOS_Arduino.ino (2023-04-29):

//This example shows how to animate graphics on a VGA screen. No backbuffering is used... just try it.
//You need to connect a VGA screen cable and an external DAC (simple R2R does the job) to the pins specified below.
//cc by-sa 4.0 license
//bitluni

#include <ESP32Lib.h>
#include <Ressources/Font6x8.h>
#include <math.h>

#include <SPI.h>
#include <Wire.h>

//pin configuration
const int redPins[] = {2, 4, 12, 13};
const int greenPins[] = {15, 16, 17, 18};
const int bluePins[] = {21, 22, 23};
const int hsyncPin = 32;
const int vsyncPin = 33;
const int clockPin = 14;
//19
//27

//VGA Device
VGA11Bit vga;

const int tvp_addr = 0x5C;  // Shown as "0xB8" in the datasheet, due to the bit shift thing (8-bit I2C address vs 7-bit).

const int fidPin = 34;
const int intPin = 35;

const int pclkPin = 32;
const int hdPin = 33;
const int vdPin = 25;
const int validPin = 26;
const int d0Pin = 27;
const int d1Pin = 14;
const int d2Pin = 12;
const int d3Pin = 13;
const int d4Pin = 22;
const int d5Pin = 21;
const int d6Pin = 17;
const int d7Pin = 16;

const int sclPin = 15;
const int sdaPin = 2;
const int rstnPin = 0;

const int spimosiPin = 23;
const int spimisoPin = 19;
const int spisclkPin = 18;

const int sdscnPin = 5;
const int flscnPin = 4;

char my_string[100];

//vspi
SPIClass * vspi = NULL;
static const int spiFreq = 30000;  // 30 KHz

void flWrite(byte addr, byte data) {
  vspi->beginTransaction(SPISettings(spiFreq, MSBFIRST, SPI_MODE0));
  digitalWrite(flscnPin, LOW);    // Pull csn low to prep other end for transfer
  vspi->transfer(addr&0x7f);      // Send the reg address. (MSB of the address stays Low for a WRITE).
  vspi->transfer(data);           // Write the data to the reg.
  vspi->endTransaction();
  digitalWrite(flscnPin, HIGH);   // Set csn high to signify end of data transfer
}

char spiRead(byte addr) {
  vspi->beginTransaction(SPISettings(spiFreq, MSBFIRST, SPI_MODE0));
  digitalWrite(flscnPin, LOW);          // Pull csn low to prep other end for transfer
  vspi->transfer( 0x80 | (addr&0x7f) ); // Set the MSB high for a READ.
  char spi_read = vspi->transfer(0x00); // Send dummy 0x00 byte, so we can read the reg back.
  vspi->endTransaction();
  digitalWrite(flscnPin, HIGH);         // Set csn high to signify end of data transfer
  return spi_read;
}

char tvp_read(char reg_addr) {
  Wire.beginTransmission(tvp_addr);
  Wire.write(reg_addr);             // Reg address to READ from.
  Wire.endTransmission();
  Wire.requestFrom(tvp_addr,1);     // Request ONE byte.
  char i2c_read = Wire.read();      // Read the byte from the buffer.
  return i2c_read;
};

char tvp_write(char reg_addr, char data) {
  Wire.beginTransmission(tvp_addr);
  Wire.write(reg_addr);             // Reg address to WRITE to.
  Wire.write(data);
  Wire.endTransmission();
};

void tvp_init() {
  uint8_t tvpreg_00 = 0x00;  // [7:2]=RES=b000000. [1]=0=AIP1A Comp, 1=A1P1B Comp. [0]=0=Comp, 1=S-Vid (bit 1 ignorred in S-Vid mode).
  uint8_t tvpreg_01 = 0x15;  // [7:5]=RES=b000. [4]=1. [3:2]=AGC Offset=b01. [1:0]=AGC Gain=b01.
  uint8_t tvpreg_02 = 0x00;  // [7:3]=RES=b00000. [2]=PLL Freeze=0. [1]=RES=0? [0]=PowerDown=0.
  uint8_t tvpreg_03 = 0x8F;  // [7]=(INT pin)=1=VBLK. [6]=0=GPCL outputs 0. [5]=0=GPCL is input. [4]=HVLK=0. [3]=YUV (TVPOE) Ena=1. [2]H/VSYNC, AVID, FID Ena=1. [1]=VBLK=0. [0]=SCLK Ena=1.

  uint8_t tvpreg_0d = 0x00;  // [7]=RES=0. [6]=YUV code range=0=ccir601. [5]=UV Code Format=0=Offset. [4:3]=YUV Bypass=b00=Normal. [2:0]=b000=ccir601 style, b111=ccir656 with embedded syncs.
  uint8_t tvpreg_0e = 0x00;  // [7:2]=RES=b000000. [1:0]=Luma trap=b00=No Notch.
  uint8_t tvpreg_0f = 0x02;  // [7]=RES. [0]=0=SCLK (YUV clock), 1=PCLK?.

  uint8_t tvpreg_c2 = 0x04;  // YUV (VDPOE) Ena=1.
  
  tvp_write(0x00, tvpreg_00);
  tvp_write(0x01, tvpreg_01);
  tvp_write(0x02, tvpreg_02);
  
  tvp_write(0x03, tvpreg_03);
  
  tvp_write(0x0d, tvpreg_0d);
  
  tvp_write(0x0e, tvpreg_0e);
  tvp_write(0x0f, tvpreg_0f);

  tvp_write(0xc2, tvpreg_c2);

  Serial.println();
  sprintf(my_string, "TVP Reg 0x00: 0x%02X. ", tvp_read(0x00)); Serial.print(my_string);
  if ( tvpreg_00&1 ) Serial.println("S-Video. AIP1A=Luma. AIP1B=Chroma.");
  else { Serial.print("Composite: "); if ( !(tvpreg_00&2) ) Serial.println("AIP1A Input."); else Serial.println("AIP1B Input."); }
  
  sprintf(my_string, "TVP Reg 0x01: 0x%02X. AGC Offset 0x%02X. AGC Gain 0x%02X.\n", tvp_read(0x01), (tvpreg_01&0xC)>>2, (tvpreg_01&3) ); Serial.print(my_string);
  
  sprintf(my_string, "TVP Reg 0x02: 0x%02X. PLL Freeze: %d. PowerDown: %d\n", tvp_read(0x02), (tvpreg_02&4), (tvpreg_02&1) ); Serial.print(my_string);
  
  sprintf(my_string, "TVP Reg 0x03: 0x%02X. VBKO: %d. GPCL: %d. GPCL_IO: %d. HVLK: %d. YUV/TVPOE: %d. HVSYNC/AVID/FID: %d. VBLK: %d. SCLK: %d.\n",
    tvp_read(0x03), (tvpreg_03&0x80)>>7, (tvpreg_03&0x40)>>6, (tvpreg_03&0x20)>>5, (tvpreg_03&0x10)>>4, (tvpreg_03&0x08)>>3, (tvpreg_03&0x04)>>2, (tvpreg_03&0x02)>>1, tvpreg_03&0x01 ); Serial.print(my_string);
  
  sprintf(my_string, "TVP Reg 0x04: 0x%02X. NTSC/PALN/PALM Autoswitch normal. \n", tvp_read(0x04)); Serial.print(my_string);
  sprintf(my_string, "TVP Reg 0x05: 0x%02X. [0]=Software Reset.\n", tvp_read(0x05)); Serial.print(my_string);
  sprintf(my_string, "TVP Reg 0x06: 0x%02X. Color Killer=Auto. Threshold=-24dB.\n", tvp_read(0x06)); Serial.print(my_string);
  sprintf(my_string, "TVP Reg 0x07: 0x%02X. Luma Processing #1.\n", tvp_read(0x07)); Serial.print(my_string);
  sprintf(my_string, "TVP Reg 0x08: 0x%02X. Luma Processing #2.\n", tvp_read(0x08)); Serial.print(my_string);
  sprintf(my_string, "TVP Reg 0x09: 0x%02X. Brightness Control.\n", tvp_read(0x09)); Serial.print(my_string);
  sprintf(my_string, "TVP Reg 0x0a: 0x%02X. Saturation Control.\n", tvp_read(0x0a)); Serial.print(my_string);
  sprintf(my_string, "TVP Reg 0x0b: 0x%02X. Hue Control.\n", tvp_read(0x0b)); Serial.print(my_string);
  sprintf(my_string, "TVP Reg 0x0c: 0x%02X. Contrast Control.\n", tvp_read(0x0c)); Serial.print(my_string);
  sprintf(my_string, "TVP Reg 0x0d: 0x%02X. Outputs and Data Rates.\n", tvp_read(0x0d)); Serial.print(my_string);
  sprintf(my_string, "TVP Reg 0x0e: 0x%02X. Luma Processing #3.\n", tvp_read(0x0e)); Serial.print(my_string);
  sprintf(my_string, "TVP Reg 0x0f: 0x%02X. Configure Shared Pins.\n", tvp_read(0x0f)); Serial.print(my_string);

  sprintf(my_string, "TVP Reg 0x84: 0x%02X. Vertical Line Count MSB.\n", tvp_read(0x84)); Serial.print(my_string);
  sprintf(my_string, "TVP Reg 0x85: 0x%02X. Vertical Line Count LSB.\n", tvp_read(0x85)); Serial.print(my_string);

  sprintf(my_string, "TVP Reg 0x86: 0x%02X. Interrupt Status Register B.\n", tvp_read(0x86)); Serial.print(my_string);
  sprintf(my_string, "TVP Reg 0x88: 0x%02X. Status Register #1.\n", tvp_read(0x88)); Serial.print(my_string);

  sprintf(my_string, "TVP Reg 0xc2: 0x%02X. Interrupt Configuration Reg A\n", tvp_read(0xc2)); Serial.print(my_string);
}

void flcos_init() {
  /*
  // JAKKS Projector power-up settings...
  flWrite(0x01, 0x15);  // [7]=RES=0. [6:5]=b00="Use Inputs for video timing"? (JAKKS).  [4:3]=DitherMode. [2:0]=DataMode b000=RGB, b101=ccir656/601.
  flWrite(0x06, 0x48);  // [7]=RES=0. [6]=VFlip=1. [5]=HFlip=0. [4]=RES=0. [3]=NSleepMode=1 SET this bit to wake up!. [2:0]=RES=b000.
  flWrite(0x0e, 0x00);  // [7:4]=RES=b0000. [3:0]=GammaValue=9=Gamma of 1.0.
  */

  flWrite(0x00, 0x01);  // MUST be set to 0x01.

  flWrite(0x01, 0x15);  // [7]=RES=0. [6:5]=b00="Use Inputs for video timing"? (JAKKS).  [4:3]=DitherMode. [2:0]=DataMode b000=RGB, b101=ccir656/601.
  
  flWrite(0x02, 0x00);  // [7:5]=VPol,HPol,ValidPol=b000=Active High,High,High. [4]=Arctic Mode?? [3:2]=RES=b00. [1:0]=VideoMask=b00 for 8-bit.
  
  flWrite(0x03, 0xFF);  // [7:6]=RES, always set to b11. [5:0]=LED Brightness=Max (0x3F).
  
  flWrite(0x04, 0x08);  // [7:4]=VldDelOffset. [3:2]=VertInterpMode. [1:0]=HVldDelay[9:8].
  flWrite(0x05, 0x00);  // [7:0]=HVldDelay[7:0].
  
  flWrite(0x06, 0x48);  // [7]=RES=0. [6]=VFlip=1. [5]=HFlip=0. [4]=RES=0. [3]=NSleepMode=1 SET this bit to wake up!. [2:0]=RES=b000.

  flWrite(0x07, 0x04);  // [7:5]=RES=b000. [4]=HScaleCycle[8]. [3:2]=VScaleStep[9:8]=b01. [1:0]=HScaleStep[9:8].
  flWrite(0x08, 0xD6);  // [7:0]=HScaleStep[7:0].
  flWrite(0x09, 0x05);  // [7:0]=HScaleCycle[7:0].
  flWrite(0x0a, 0xDE);  // [7:0]=VScaleStep[7:0].
  flWrite(0x0b, 0x0E);  // [7:0]=VScaleCycle[7:0].

  flWrite(0x0e, 0x00);  // [7:4]=RES=b0000. [3:0]=GammaValue=0=Gamma of 1.0.  // JAKKS.
  //flWrite(0x0e, 0x09);  // [7:4]=RES=b0000. [3:0]=GammaValue=9=Gamma of 2.1.    // Guessed.
  
  // 288 lines per field PAL...
  uint16_t hscalestep = 214;  // H Coef.
  uint16_t hscalecycle = 5;   // H Cycle.
  uint16_t vscalestep = 399;  // V Coef.
  uint16_t vscalecycle = 7;   // V Cycle.
  
  uint8_t flreg07 = ((hscalecycle&0x100)>>4) | ((vscalestep&0x300)>>6) | ((hscalestep&0x300)>>8);
  uint8_t flreg08 = hscalestep  & 0xff;
  uint8_t flreg09 = hscalecycle & 0xff;
  uint8_t flreg0a = vscalestep  & 0xff;
  uint8_t flreg0b = vscalecycle & 0xff;
  flWrite(0x07, flreg07);  // [7:5]=RES=b000. [4]=HScaleCycle[8]. [3:2]=VScaleStep[9:8]=b01. [1:0]=HScaleStep[9:8].
  flWrite(0x08, flreg08);  // [7:0]=HScaleStep[7:0].
  flWrite(0x09, flreg09);  // [7:0]=HScaleCycle[7:0].
  flWrite(0x0a, flreg0a);  // [7:0]=VScaleStep[7:0].
  flWrite(0x0b, flreg0b);  // [7:0]=VScaleCycle[7:0].
  
  flWrite(0x0c, 0x01);  // [7:0]=VVldDelay[7:0].
  flWrite(0x0d, 0x00);  // [7:4]=RES=b0000. [3:0]=CinemaLines=b0000.
  flWrite(0x0e, 0x09);  // [7:4]=RES=b0000. [3:0]=GammaValue=9=Gamma of 2.1.

  
  // Color Space Gain registers...
  /*
  flWrite(0x0f, 0x00);  // [7:0]=
  flWrite(0x10, 0x00);  // [7:0]=
  flWrite(0x11, 0x00);  // [7:0]=
  flWrite(0x12, 0x00);  // [7:0]=
  flWrite(0x13, 0x00);  // [7:0]=
  flWrite(0x14, 0x00);  // [7:0]=
  flWrite(0x15, 0x00);  // [7:0]=
  flWrite(0x16, 0x00);  // [7:0]=
  flWrite(0x17, 0x00);  // [7:0]=

  flWrite(0x18, 0x54);  // [7:4]=Resolution=5. [3:0]=Revision=4.

  // Color Space Offset registers...
  flWrite(0x19, 0x00);  // [7:0]=
  flWrite(0x1a, 0x00);  // [7:0]=
  flWrite(0x1b, 0x00);  // [7:0]=

  flWrite(0x1c, 0x2f);  // [7]=RES=0. [6:0]=MinVFreq[6:0]=0x2F.
  flWrite(0x1d, 0x3f);  // [7]=RES=0. [6:0]=MaxVFreq[6:0]=0x3F.
  */
  delay(50);
  
  Serial.println();
  sprintf(my_string, "FLCOS Reg 0x00: 0x%02X\n", spiRead(0x00)); Serial.print(my_string);
  sprintf(my_string, "FLCOS Reg 0x01: 0x%02X\n", spiRead(0x01)); Serial.print(my_string);
  sprintf(my_string, "FLCOS Reg 0x02: 0x%02X\n", spiRead(0x02)); Serial.print(my_string);
  sprintf(my_string, "FLCOS Reg 0x03: 0x%02X\n", spiRead(0x03)); Serial.print(my_string);
  sprintf(my_string, "FLCOS Reg 0x04: 0x%02X\n", spiRead(0x04)); Serial.print(my_string);
  sprintf(my_string, "FLCOS Reg 0x05: 0x%02X\n", spiRead(0x05)); Serial.print(my_string);
  sprintf(my_string, "FLCOS Reg 0x06: 0x%02X\n", spiRead(0x06)); Serial.print(my_string);
  sprintf(my_string, "FLCOS Reg 0x07: 0x%02X\n", spiRead(0x07)); Serial.print(my_string);
  sprintf(my_string, "FLCOS Reg 0x08: 0x%02X\n", spiRead(0x08)); Serial.print(my_string);
  sprintf(my_string, "FLCOS Reg 0x09: 0x%02X\n", spiRead(0x09)); Serial.print(my_string);
  sprintf(my_string, "FLCOS Reg 0x0a: 0x%02X\n", spiRead(0x0a)); Serial.print(my_string);
  sprintf(my_string, "FLCOS Reg 0x0b: 0x%02X\n", spiRead(0x0b)); Serial.print(my_string);
  sprintf(my_string, "FLCOS Reg 0x0c: 0x%02X\n", spiRead(0x0c)); Serial.print(my_string);
  sprintf(my_string, "FLCOS Reg 0x0d: 0x%02X\n", spiRead(0x0d)); Serial.print(my_string);
  sprintf(my_string, "FLCOS Reg 0x0e: 0x%02X\n", spiRead(0x0e)); Serial.print(my_string);
  sprintf(my_string, "FLCOS Reg 0x0f: 0x%02X\n", spiRead(0x0f)); Serial.print(my_string);

  /*
  sprintf(my_string, "FLCOS Reg 0x10: 0x%02X\n", spiRead(0x10)); Serial.print(my_string);
  sprintf(my_string, "FLCOS Reg 0x11: 0x%02X\n", spiRead(0x11)); Serial.print(my_string);
  sprintf(my_string, "FLCOS Reg 0x12: 0x%02X\n", spiRead(0x12)); Serial.print(my_string);
  sprintf(my_string, "FLCOS Reg 0x13: 0x%02X\n", spiRead(0x13)); Serial.print(my_string);
  sprintf(my_string, "FLCOS Reg 0x14: 0x%02X\n", spiRead(0x14)); Serial.print(my_string);
  sprintf(my_string, "FLCOS Reg 0x15: 0x%02X\n", spiRead(0x15)); Serial.print(my_string);
  sprintf(my_string, "FLCOS Reg 0x16: 0x%02X\n", spiRead(0x16)); Serial.print(my_string);
  sprintf(my_string, "FLCOS Reg 0x17: 0x%02X\n", spiRead(0x17)); Serial.print(my_string);
  sprintf(my_string, "FLCOS Reg 0x18: 0x%02X\n", spiRead(0x18)); Serial.print(my_string);
  sprintf(my_string, "FLCOS Reg 0x19: 0x%02X\n", spiRead(0x19)); Serial.print(my_string);
  sprintf(my_string, "FLCOS Reg 0x1a: 0x%02X\n", spiRead(0x1a)); Serial.print(my_string);
  sprintf(my_string, "FLCOS Reg 0x1b: 0x%02X\n", spiRead(0x1b)); Serial.print(my_string);
  sprintf(my_string, "FLCOS Reg 0x1c: 0x%02X\n", spiRead(0x1c)); Serial.print(my_string);
  sprintf(my_string, "FLCOS Reg 0x1d: 0x%02X\n", spiRead(0x1d)); Serial.print(my_string);
  sprintf(my_string, "FLCOS Reg 0x1e: 0x%02X\n", spiRead(0x1e)); Serial.print(my_string);
  sprintf(my_string, "FLCOS Reg 0x1f: 0x%02X\n", spiRead(0x1f)); Serial.print(my_string);
  */
  Serial.println();
}

//initial setup
void setup()
{
  pinMode(fidPin, INPUT);
  pinMode(intPin, INPUT);

  pinMode(pclkPin, INPUT);
  pinMode(hdPin, INPUT);
  pinMode(vdPin, INPUT);
  pinMode(validPin, INPUT);
  pinMode(d0Pin, INPUT);
  pinMode(d1Pin, INPUT);
  pinMode(d2Pin, INPUT);
  pinMode(d3Pin, INPUT);
  pinMode(d4Pin, INPUT);
  pinMode(d5Pin, INPUT);
  pinMode(d6Pin, INPUT);
  pinMode(d7Pin, INPUT);

  pinMode(sclPin, INPUT);
  pinMode(sdaPin, INPUT);

  pinMode(spimosiPin, OUTPUT);
  pinMode(spimisoPin, INPUT_PULLUP);
  pinMode(spisclkPin, OUTPUT);

  pinMode(sdscnPin, OUTPUT);
  digitalWrite(sdscnPin, HIGH);
  
  pinMode(flscnPin, OUTPUT);
  digitalWrite(flscnPin, HIGH);

  Serial.begin(115200);

  Wire.begin (sdaPin, sclPin);

  vspi = new SPIClass(VSPI);
  vspi->begin(spisclkPin, spimisoPin, spimosiPin, flscnPin);

  pinMode(rstnPin, OUTPUT);
  digitalWrite(rstnPin, LOW);   // Reset FLCOS and TVP for 100ms.
  delay(100);
  digitalWrite(rstnPin, HIGH);  // Bring FLCOS and TVP out of reset.
  delay(100);

  flcos_init();
  delay(100);
  tvp_init();

  uint8_t stat1;
  uint8_t stat1_old = 0xde;  // Random byte, to trigger the first printf. (TVP Status Reg often starts at 0x00, so we need any different value in stat1_old).

  uint8_t stat5;
  uint8_t stat5_old = 0xde;  // Random byte, to trigger the first printf. (TVP Status Reg often starts at 0x00, so we need any different value in stat5_old).

  while (1) {
    stat1 = tvp_read(0x88);
    if ( stat1 != stat1_old ) {
      sprintf(my_string, "TVP Reg 0x88: 0x%02X. Status Register #1. Peak: %d. Alt: %d. 50Hz: %d. Lost: %d. Color: %d. Vsync: %d. Hsync: %d. VCR: %d.\n",
        stat1, (stat1&0x80)>>7, (stat1&0x40)>>6, (stat1&0x20)>>5, (stat1&0x10)>>4, (stat1&0x08)>>3, (stat1&0x04)>>2, (stat1&0x02)>>1, (stat1&0x01) ); Serial.print(my_string); 
    }
    stat1_old = stat1;

    stat5 = tvp_read(0x8c);
    if ( stat5 != stat5_old ) {
      sprintf(my_string, "TVP Reg 0x8c: 0x%02X. Status Register #5. Autoswitch: %d. ", stat5, (stat5&0x80)>>7 ); Serial.print(my_string);
      switch ( stat5&0xF ) {
        case 1: sprintf(my_string, "(M) NTSC ITU−R BT.601           \n"); break;
        case 3: sprintf(my_string, "(B, G, H, I, N) PAL ITU−R BT.601\n"); break;
        case 5: sprintf(my_string, "(M) PAL ITU−R BT.601            \n"); break;
        case 7: sprintf(my_string, "(Combination-N) ITU−R BT.601    \n"); break;
        case 9: sprintf(my_string, "NTSC 4.43 ITU−R BT.601          \n"); break;
        default: sprintf(my_string, "Reserved.\n"); break;
      }
      Serial.print(my_string);
    }
    stat5_old = stat5;

    delay(500);
  }

  /*
  uint16_t hvid_start = 0;
  uint16_t hvid_stop = 0;

  uint8_t vvid_start = 0;
  uint8_t vvid_stop = 0;
  while(1) {
    tvp_write(0x11, hvid_start>>2);   // Write MSB bits [9:8] first. (have to shift RIGHT, to get MSB bit 9 into reg bit 7).
    tvp_write(0x12, hvid_start&3);    // Write LSB bits [7:0] to update the value.
    
    tvp_write(0x13, hvid_stop>>2);   // Write MSB bits [9:8] first. (have to shift RIGHT, to get MSB bit 9 into reg bit 7).
    tvp_write(0x14, hvid_stop&3);    // Write LSB bits [7:0] to update the value.
    
    sprintf(my_string, "hvid_start: %03d. hvid_stop: %03d. vvid_start: %02d. vvid_stop: %02d\n", hvid_start, hvid_stop, vvid_start, vvid_stop); Serial.print(my_string);
    delay(100);
    hvid_start++;
    if (hvid_start==511) {
      hvid_start = 0;
      vvid_start++;
    }
  }
  */

  /*
  while (1) {
    sprintf(my_string, "TVP Reg 0x88: 0x%02X. Status Register #1.\n", tvp_read(0x88)); Serial.print(my_string);
    delay(1000);
  }
  */
 
  /*
  //initializing i2s vga (with only one framebuffer)
  vga.init(vga.MODE200x150, redPins, greenPins, bluePins, hsyncPin, vsyncPin, clockPin);
  //setting the font
  vga.setFont(Font6x8);
  */
}

//the loop is done every frame
void loop()
{
  /*
  //setting the text cursor to the lower left corner of the screen
  vga.setCursor(0, vga.yres - 8);
  //setting the text color to white with opaque black background
  vga.setTextColor(vga.RGB(0xffffff), vga.RGBA(0, 0, 0, 255));
  //printing the fps
  vga.print("fps: ");
  static long f = 0;
  vga.print(long((f++ * 1000) / millis()));

  //circle parameters
  float factors[][2] = {{1, 1.1f}, {0.9f, 1.02f}, {1.1, 0.8}};
  int colors[] = {vga.RGB(0xff0000), vga.RGB(0x00ff00), vga.RGB(0x0000ff)};
  //animate them with milliseconds
  float p = millis() * 0.002f;
  for (int i = 0; i < 3; i++)
  {
    //calculate the position
    int x = vga.xres / 2 + sin(p * factors[i][0]) * vga.xres / 3;
    int y = vga.yres / 2 + cos(p * factors[i][1]) * vga.yres / 3;
    //clear the center with a black filled circle
    vga.fillCircle(x, y, 8, 0);
    //draw the circle with the color from the array
    vga.circle(x, y, 10, colors[i]);
  }
  //render the flame effect
  for (int y = 0; y < vga.yres - 9; y++)
    for (int x = 1; x < vga.xres - 1; x++)
    {
      //take the avarage from the surrounding pixels below
      int c0 = vga.get(x, y);
      int c1 = vga.get(x, y + 1);
      int c2 = vga.get(x - 1, y + 1);
      int c3 = vga.get(x + 1, y + 1);
      int r = ((c0 & 0x1f) + (c1 & 0x1f) + ((c2 & 0x1f) + (c3 & 0x1f)) / 2) / 3;
      int g = (((c0 & 0x3e0) + (c1 & 0x3e0) + ((c2 & 0x3e0) + (c3 & 0x3e0)) / 2) / 3) & 0x3e0;
      int b = (((c0 & 0x3c00) + (c1 & 0x3c00) + ((c2 & 0x3c00) + (c3 & 0x3c00)) / 2) / 3) & 0x3c00;
      //draw the new pixel
      vga.dotFast(x, y, r | g | b);
    }
   */
}

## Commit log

2022-10-03 Add images to README
    [FLCOS Projector Driver.sch]
2022-10-03 added pullups to I2C
    [FLCOS Projector Driver.brd, FLCOS Projector Driver.sch]
2022-10-03 RGB LED current set to 156mA
    [FLCOS Projector Driver.brd, FLCOS Projector Driver.sch]
2022-10-03 schematic tweaks
    [FLCOS Projector Driver.brd, FLCOS Projector Driver.sch]
2022-10-04 Allow USB/GPIO0 to reset TVP and FLCOS
    [FLCOS Projector Driver.brd, FLCOS Projector Driver.sch]
2022-10-04 GPIO0 to reset the TVP, ESP_EN_N to reset the FLCOS
    [FLCOS Projector Driver.brd, FLCOS Projector Driver.sch]
2022-10-04 README update
    [FLCOS Projector Driver.brd, FLCOS Projector Driver.sch]
2022-10-04 Added pulldown on FL_D7, to set I2C Addr
    [FLCOS Projector Driver.brd]
2022-10-04 removed erroneous polys from tStop layer. Fixed 3V3 reg vias
    [FLCOS Projector Driver.brd, FLCOS Projector Driver.sch]
2022-10-04 Started BOM. Changing parts to Mouser in-stock
    [FLCOS Projector BOM 5-10-22.xlsx, FLCOS Projector Driver.brd, FLCOS Projector Driver.sch]
2022-10-05 ERC and DRC passed. BOM not quite done
    [FLCOS Projector BOM 5-10-22.xlsx, FLCOS Projector Driver.brd, FLCOS Projector Driver.sch]
2022-10-05 Changed to USB-C. BOM passives not done yet
    [FLCOS Projector BOM 5-10-22.xlsx, FLCOS Projector Driver.brd, FLCOS Projector Driver.sch]
2022-10-05 Changed Composite pin header for TRRS socket
    [FLCOS Projector BOM 5-10-22.xlsx, FLCOS Projector Driver.brd, FLCOS Projector Driver.sch]
2022-10-05 Fixed FLCOS mounting hole position vs flex
    [FLCOS Projector Driver.brd]
2022-10-05 Proto PCBs and stencil ordered. Passives BOM not done
    [FLCOS Projector Driver.brd]
2022-10-06 XLSX BOM finished. Tweaked FLCOS mounting points
    [FLCOS Projector BOM 5-10-22.xlsx, FLCOS Projector Driver.brd, FLCOS Projector Driver.sch]
2022-10-06 Added Mouser cart XLS. BOM tweaks due to low stocks
    [FLCOS Projector BOM 5-10-22.xlsx, FLCOS Projector Driver.brd, FLCOS Projector Driver.sch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]
2022-10-15 Changed R11 to a pull-up for FLCOS_SOUT
    [FLCOS Projector BOM 5-10-22.xlsx, FLCOS Projector Driver.brd, FLCOS Projector Driver.sch]
2023-04-29 Added Arduino ESP32 Project folder
2023-04-29 Added inverter transistors for RGB LED PWM signals
    [FLCOS Projector Driver.brd, FLCOS Projector Driver.sch]
2023-04-29 PCB changes to fix auto-reset during Flash programming
    [FLCOS Projector Driver.brd, FLCOS Projector Driver.sch]
2023-04-29 Added JST PH fan header
    [FLCOS Projector Driver.brd, FLCOS Projector Driver.sch]
2023-04-29 Added images. Updated README
    [FLCOS Projector Driver.brd, FLCOS Projector Driver.sch]
2023-04-29 Added image of built board/projector
2024-10-13 Fixed the CC 5K1 pull-down resistors on USB-C. They used to be 22K pull-ups!
    [FLCOS Projector Driver.brd, FLCOS Projector Driver.sch]

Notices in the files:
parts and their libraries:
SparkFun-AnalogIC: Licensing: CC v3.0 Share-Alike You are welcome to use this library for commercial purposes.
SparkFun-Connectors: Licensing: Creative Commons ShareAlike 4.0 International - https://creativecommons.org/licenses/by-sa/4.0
